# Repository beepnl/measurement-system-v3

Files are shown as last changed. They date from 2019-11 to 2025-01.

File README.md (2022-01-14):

# BEEP - base v3
This is a repo containing the files to create the open source hardware for the Beep measurement system version 3.

This version features a:

- Stainless steel (easy to assemble) frame
- 1 weight sensor
- 1-5 temperature sensors
- 1 mic for on board audio FFT analysis
- Custom developed PCB (by Ideetron) with Nordic nRF BLE and LoRa

The BEEP base is part of the complete [BEEP system](https://github.com/beepnl/BEEP)

## Measurement system parts

The measurement system frame holds the weight sensor and the electonics box housing, and functions as a stiff weighing frame construction.

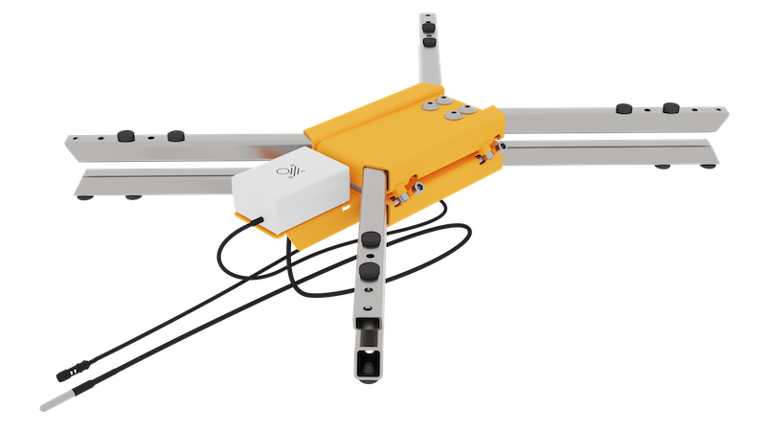
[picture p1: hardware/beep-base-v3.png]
BEEP base v3


### hardware/frame
The folder 'frame' contains the drawings of the stainless steel parts and the standard waterproof casing drill holes. 

### hardware/pcb
The pcb of the measurement system contains a lot of features, that can be seen in the image below:
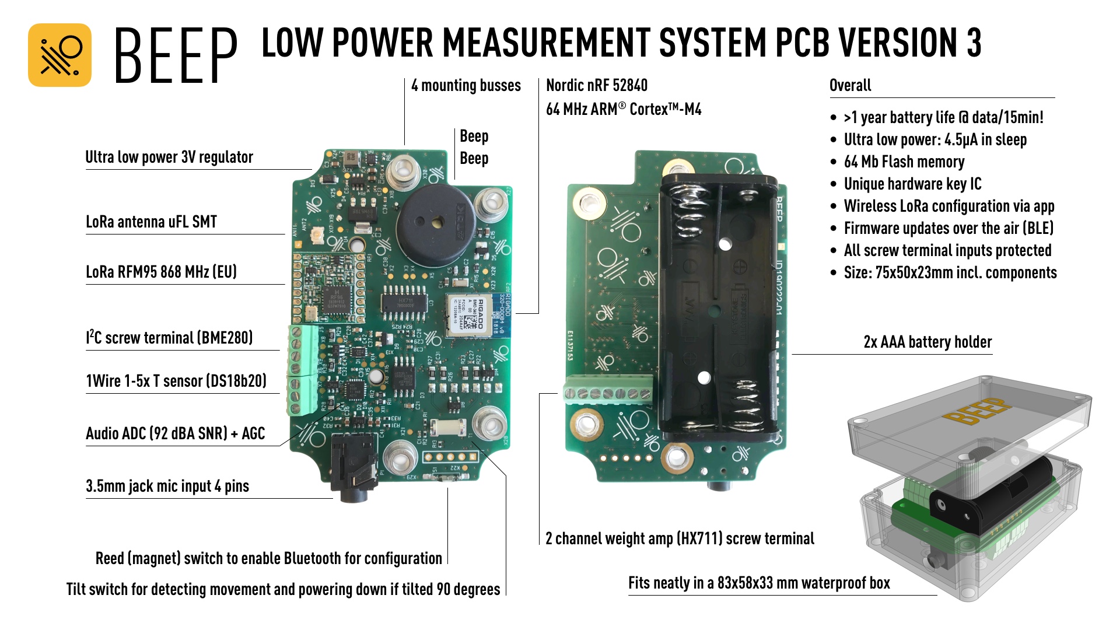
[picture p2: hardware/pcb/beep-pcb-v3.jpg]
BEEP base - PCB v3


The folder contains the gerber files and the schematic. A print layout is added to see find the exact wire locations of the screw terminals

With the Gerber files, you can directly order a PCB. It contains all files required for the manufacturing of the PCB. 

## Assembly

The assembly is straight forward and can be seen in this video:
[BEEP base - Assembly](https://youtu.be/ZGfoobvGa-Y)

## Firmware
The firmware for the BEEP base v3 PCB is available at: https://github.com/beepnl/beep-base-firmware

## Improvements
If you have improvements, or ideas for creating a better frame, please subscribe to our [Slack channel](beep-global.slack.com) explaining your thoughts. 

Or just fork this repo, and do a pull request with you adjustments, or additions.

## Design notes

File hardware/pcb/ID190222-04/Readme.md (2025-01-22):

# Changes ID190222-04

- More space for J6 (1 wire 3 pin header)
- Through holes for S1 (on/off switch) bigger
- Version number bump to ID190222-04

NB: The component placement file is the .rep file

# PCB layout

## Top
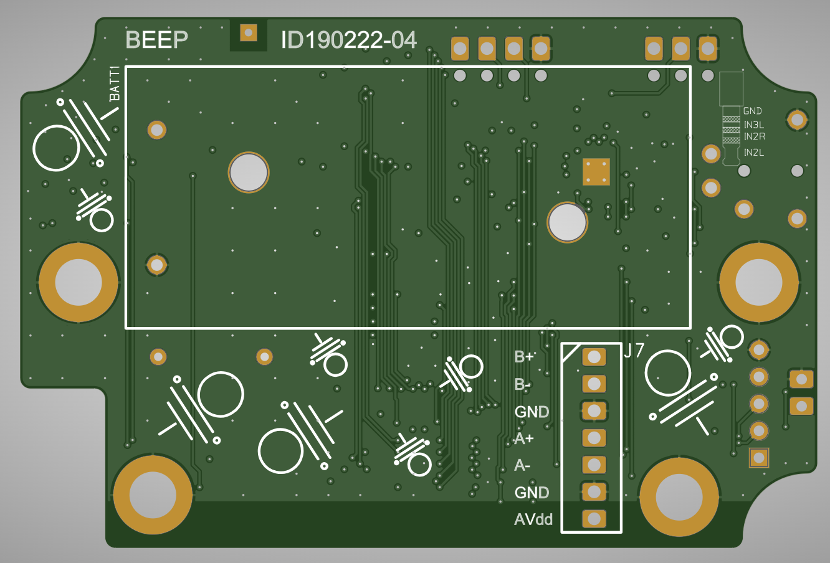
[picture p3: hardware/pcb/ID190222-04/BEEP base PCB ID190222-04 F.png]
PCB top


## Bottom
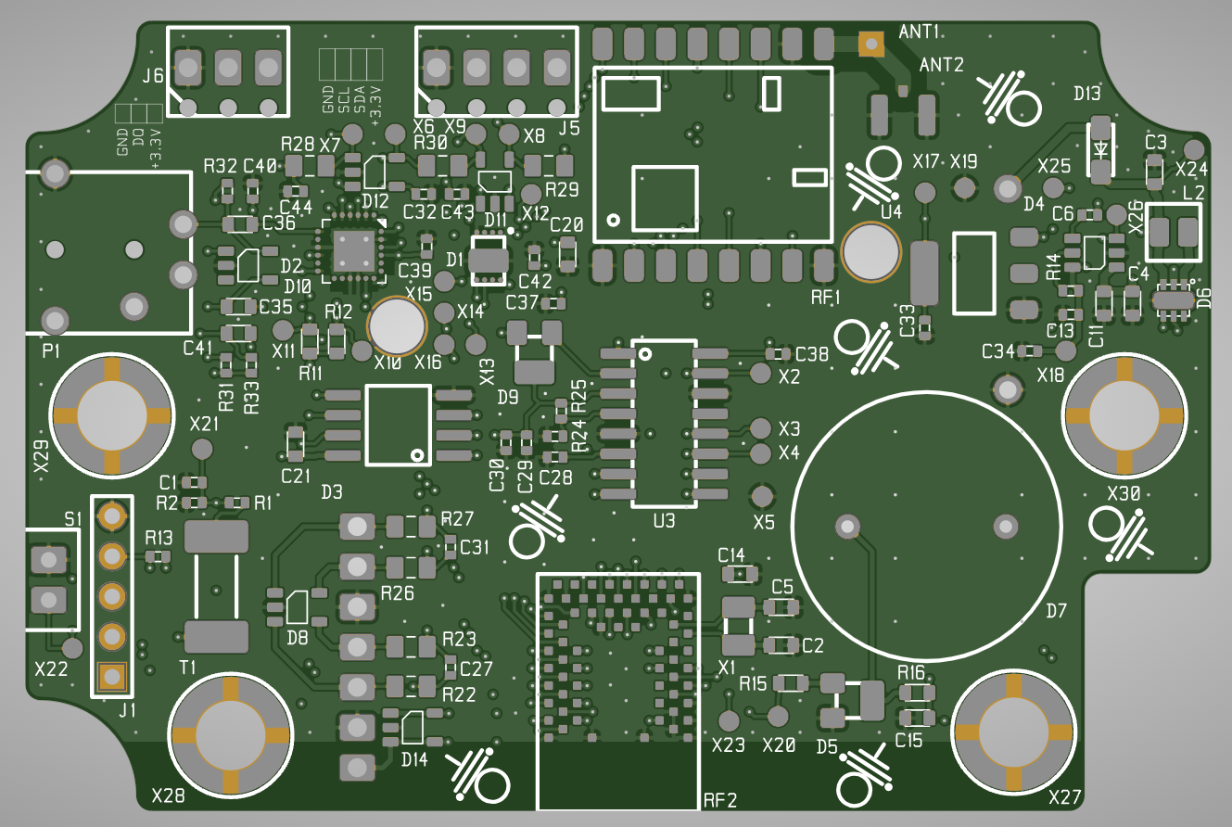
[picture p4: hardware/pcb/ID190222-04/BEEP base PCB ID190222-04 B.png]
PCB bottom


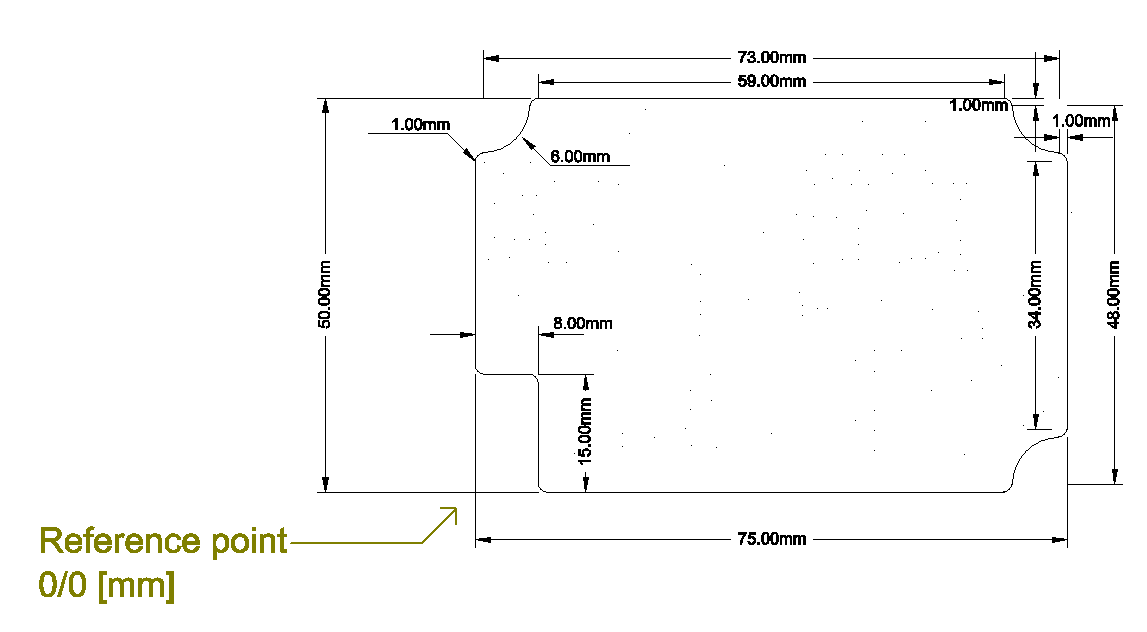
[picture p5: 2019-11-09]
hardware/pcb/pcb-size.png

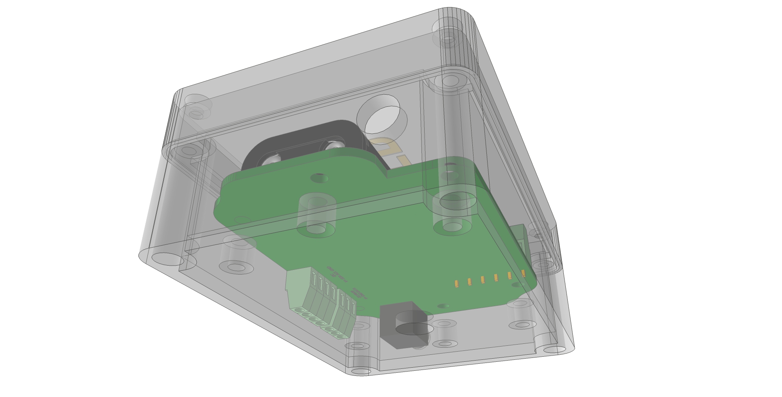
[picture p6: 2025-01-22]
hardware/frame/2019-11-01/beep-pcb-v3-in-box.jpg

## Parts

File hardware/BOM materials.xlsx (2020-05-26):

NB | Amount | DESCRIPTION | MANUFACTURER | TYPE | SUPPLIER | REMARK
1 | 1 | Loadcell | Bosche | H40A a 150KG | bosche.eu | Any 4 wire loadcell will work. However the by us selected loadcell has the most stable results we found
2 | 1 | Temperature Sensor |  | DS20B18 |  | This is a 1 wire system, you can add up to 5 sensors in parallel without any problems.
3 | 1 | Microphone |  | Lavalier Condenser Microphones 3.5mm | https://www.aliexpress.com/item/33003154464.html | TLV320ADC3100 is used as AD converter, any 3 or 4 pin 3,5mm electret microphone will work
4 | 2 | Bateries | Enigizer | L92 |  | Please use 1,5v lithuim cells to ensure you can use the scale for at least a year on one set of batteries when measuring and sending data every 15 minutes

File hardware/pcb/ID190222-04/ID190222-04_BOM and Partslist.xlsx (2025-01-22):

 | donderdag 27 oktober 2022
 | ID190222-03
 | Total number of components: | 82
NB | REF | VALUE | DESCRIPTION | MANUFACTURER | TYPE | SUPPLIER | ORDER CODE | CLASS | REMARK
1 | R14 | 0E_0402 | Resistor 0E 0402 63mW | Vishay | CRCW04020000Z0ED | Farnell | 1469661 | 1
4 | R22 | 100E_0805 | Resistor 100E 1% 0.1W C0805 | Vishay | CRCW0805100RFKEAHP | Farnell | 1738946 | 1
 | R23 | 100E_0805 | Resistor 100E 1% 0.1W C0805 | Vishay | CRCW0805100RFKEAHP | Farnell | 1738946 | 1
 | R26 | 100E_0805 | Resistor 100E 1% 0.1W C0805 | Vishay | CRCW0805100RFKEAHP | Farnell | 1738946 | 1
 | R27 | 100E_0805 | Resistor 100E 1% 0.1W C0805 | Vishay | CRCW0805100RFKEAHP | Farnell | 1738946 | 1
13 | C13 | 100nF 0402 | Capacitor Ceramic 100nF X7R 0402 | TDK | C1005X7R1E104K050BB | Farnell | 2525045 | 1
 | C27 | 100nF 0402 | Capacitor Ceramic 100nF X7R 0402 | TDK | C1005X7R1E104K050BB | Farnell | 2525045 | 1
 | C28 | 100nF 0402 | Capacitor Ceramic 100nF X7R 0402 | TDK | C1005X7R1E104K050BB | Farnell | 2525045 | 1
 | C29 | 100nF 0402 | Capacitor Ceramic 100nF X7R 0402 | TDK | C1005X7R1E104K050BB | Farnell | 2525045 | 1
 | C31 | 100nF 0402 | Capacitor Ceramic 100nF X7R 0402 | TDK | C1005X7R1E104K050BB | Farnell | 2525045 | 1
 | C32 | 100nF 0402 | Capacitor Ceramic 100nF X7R 0402 | TDK | C1005X7R1E104K050BB | Farnell | 2525045 | 1
 | C37 | 100nF 0402 | Capacitor Ceramic 100nF X7R 0402 | TDK | C1005X7R1E104K050BB | Farnell | 2525045 | 1
 | C38 | 100nF 0402 | Capacitor Ceramic 100nF X7R 0402 | TDK | C1005X7R1E104K050BB | Farnell | 2525045 | 1
 | C39 | 100nF 0402 | Capacitor Ceramic 100nF X7R 0402 | TDK | C1005X7R1E104K050BB | Farnell | 2525045 | 1
 | C40 | 100nF 0402 | Capacitor Ceramic 100nF X7R 0402 | TDK | C1005X7R1E104K050BB | Farnell | 2525045 | 1
 | C42 | 100nF 0402 | Capacitor Ceramic 100nF X7R 0402 | TDK | C1005X7R1E104K050BB | Farnell | 2525045 | 1
 | C43 | 100nF 0402 | Capacitor Ceramic 100nF X7R 0402 | TDK | C1005X7R1E104K050BB | Farnell | 2525045 | 1
 | C44 | 100nF 0402 | Capacitor Ceramic 100nF X7R 0402 | TDK | C1005X7R1E104K050BB | Farnell | 2525045 | 1
1 | C6 | 100pF 0402 | Capacitor Ceramic 100pF C0G 0402 | Kemet | C0402C101K3GACTU | Farnell | 2581019 | 1
2 | R13 | 10K0_0402 | Resistor 10K0 5% 0.0625W C0402 | Tyco | CRG0402J10K-10 | Farnell | 1174160 | 1
 | R25 | 10K0_0402 | Resistor 10K0 5% 0.0625W C0402 | Tyco | CRG0402J10K-10 | Farnell | 1174160 | 1
1 | C1 | 10nF 0402 | Capacitor Ceramic 10NF X7R 0402 | Murata | GRM155R71H103KA88D | Farnell | 1828887 | 1
3 | C30 | 10uF 0402 6.3V | Capacitor Ceramic 10u X5R 0402 | muRata | GRM155R60J106ME44D | Farnell | 2666402 | 1
 | C33 | 10uF 0402 6.3V | Capacitor Ceramic 10u X5R 0402 | muRata | GRM155R60J106ME44D | Farnell | 2666402 | 1
 | C34 | 10uF 0402 6.3V | Capacitor Ceramic 10u X5R 0402 | muRata | GRM155R60J106ME44D | Farnell | 2666402 | 1
4 | C11 | 10uF 0603 | Capacitor Ceramic 10uF X5R 0603 | TDK | C1608X5R1E106M080AC | Farnell | 2525099 | 1
 | C15 | 10uF 0603 | Capacitor Ceramic 10uF X5R 0603 | TDK | C1608X5R1E106M080AC | Farnell | 2525099 | 1
 | C3 | 10uF 0603 | Capacitor Ceramic 10uF X5R 0603 | TDK | C1608X5R1E106M080AC | Farnell | 2525099 | 1
 | C4 | 10uF 0603 | Capacitor Ceramic 10uF X5R 0603 | TDK | C1608X5R1E106M080AC | Farnell | 2525099 | 1
1 | R1 | 1k00_0402 | Resistor 1k00 C0402 1% 0.063W | Walsin | WR04X1001FTL | Farnell | 2502496 | 1
4 | R11 | 1k20_0603 | Resistor 1k20 C0603 1% 0.1W | Panasonic | ERJ3EKF1201V | Farnell | 2303150 | 1
 | R12 | 1k20_0603 | Resistor 1k20 C0603 1% 0.1W | Panasonic | ERJ3EKF1201V | Farnell | 2303150 | 1
 | R15 | 1k20_0603 | Resistor 1k20 C0603 1% 0.1W | Panasonic | ERJ3EKF1201V | Farnell | 2303150 | 1
 | R16 | 1k20_0603 | Resistor 1k20 C0603 1% 0.1W | Panasonic | ERJ3EKF1201V | Farnell | 2303150 | 1
2 | C20 | 220NF 25V 0603 | Capacitor Ceramic 220nF SMD 0603 25V | Epcos | B37931K0224K60 | Farnell | 8805644 | 1
 | C21 | 220NF 25V 0603 | Capacitor Ceramic 220nF SMD 0603 25V | Epcos | B37931K0224K60 | Farnell | 8805644 | 1
1 | BATT1 | 2468 | Battery holder for 2AAA batteries | Kyestone | 2468 | Farnell | 1650679 | 2
3 | R31 | 2k2_0402 | Resistor 2k2 1% 63mW C0402 | Vishay | CRCW04022K20FKED | Farnell | 2140802 | 1
 | R32 | 2k2_0402 | Resistor 2k2 1% 63mW C0402 | Vishay | CRCW04022K20FKED | Farnell | 2140802 | 1
 | R33 | 2k2_0402 | Resistor 2k2 1% 63mW C0402 | Vishay | CRCW04022K20FKED | Farnell | 2140802 | 1
1 | P1 | 3.5MM JACK | 3.5mm Audio Jack Connector THT 4-positions | CUI | 3.5mm_Jack | Mouser | 490-SJ-43515TS | 2
1 | R2 | 3M3_0402 | Resistor 3M30 C0402 1% 0.063W | Vishay | CRCW04023M30FKED | Farnell | 2141102 | 1
1 | L2 | 3U3H-1.7A | Spoel 3.3 uH 1.7A 3x3 | Wurth | WE-MAPI | Farnell | 2361920 | 2
3 | C35 | 470NF 0603 | Capacitor Ceramic 470NF X7R 0603 | TDK | C1608X7R1H474K080AC | Farnell | 2346908 | 1
 | C36 | 470NF 0603 | Capacitor Ceramic 470NF X7R 0603 | TDK | C1608X7R1H474K080AC | Farnell | 2346908 | 1
 | C41 | 470NF 0603 | Capacitor Ceramic 470NF X7R 0603 | TDK | C1608X7R1H474K080AC | Farnell | 2346908 | 1
3 | R28 | 4K70_0805 | Resistor 4K70 1% 0.1W C0805 | Vishay | CRCW08054K70FKEA | Farnell | 1469923 | 1
 | R29 | 4K70_0805 | Resistor 4K70 1% 0.1W C0805 | Vishay | CRCW08054K70FKEA | Farnell | 1469923 | 1
 | R30 | 4K70_0805 | Resistor 4K70 1% 0.1W C0805 | Vishay | CRCW08054K70FKEA | Farnell | 1469923 | 1
1 | C14 | 4U7 0603 | Capacitor Ceramic 4u7 X7R 0603 | TDK | C1608X7S1A475K080AC | Farnell | 2528771 | 1
2 | C2 | 6pF 0603 | Capacitor Ceramic 6pF NP0 0603 | Walsin | 0603N6R0D500CT | Farnell | 2496912 | 1
 | C5 | 6pF 0603 | Capacitor Ceramic 6pF NP0 0603 | Walsin | 0603N6R0D500CT | Farnell | 2496912 | 1
1 | R24 | 8k2_0402 | Resistor 8k2 0402 63mW | Vishay | CRCW04028K20FKED | Farnell | 2140851 | 1
1 | D1 | ATECC608A-MAHDA | CryptoAuthentication Devie | Microchip | ATECC608-MAHDA | Mouser | 556-ATECC608AMAHDAS | 2
1 | D5 | BC850C | NPN general purpose transistor | NPX | BC850C | Farnell | 1081241 | 2
1 | RF2 | BMD-340 | nRF52840 device Rigado | Rigado | 377-BMD-340-A-R | Mouser | BMD-340-A-R | 2
1 | ANT2 | CL331-0471 | U-FL connector SMD | Hirose | CL331-0471 | Fanell | CL331-0471 | 2
1 | D13 | CRS08 | Schottky diode 1.5A 30V 360mV | Toshiba | CRS08 | Farnell | 1300796 | 2
5 | D11 | ESDS304DBVR | 4-Channel ESD diode 3.6Vrwm SOT23-5 | Texas Instruments | ESDS304DBVR | Mouser | 595-ESDS304DBVR | 2
 | D12 | ESDS304DBVR | 4-Channel ESD diode 3.6Vrwm SOT23-5 | Texas Instruments | ESDS304DBVR | Mouser | 595-ESDS304DBVR | 2
 | D14 | ESDS304DBVR | 4-Channel ESD diode 3.6Vrwm SOT23-5 | Texas Instruments | ESDS304DBVR | Mouser | 595-ESDS304DBVR | 2
 | D2 | ESDS304DBVR | 4-Channel ESD diode 3.6Vrwm SOT23-5 | Texas Instruments | ESDS304DBVR | Mouser | 595-ESDS304DBVR | 2
 | D8 | ESDS304DBVR | 4-Channel ESD diode 3.6Vrwm SOT23-5 | Texas Instruments | ESDS304DBVR | Mouser | 595-ESDS304DBVR | 2
1 | U3 | HX711 | 24-Bit Analog-to-Digital Converter (ADC) | AVIA SEMICONDUCTOR | HX711 | - | HX711 | 2
1 | D9 | MMBT4403 | PNP transistor SOT23-3 | Diodes | MMBT4403 | Farnell | 2061460 | 2
1 | J6 | MPT0.5-3_2.54 | 3 polige pinheader 2.54mm raster Phoenix 1725669 | Phoenix | MPT0.5-3_2.54 | Phoenix | 1725669 | 2
1 | J5 | MPT0.5-4_2.54 | 4 polige pinheader 2.54mm raster Phoenix 1725672 | Phoenix | MPT0.5-4_2.54 | Phoenix | 1725672 | 2
1 | J7 | MPT0.5-7_2.54 | 7 polige pinheader 2.54mm raster Phoenix 1725708 | Phoenix | MPT0.5-7_2.54 | Phoenix | 1725708 | 2
1 | D3 | MX25R6435F | Flash Memory Serial NOR 64 Mbit SPI SOP-8 | Macronix | MX25R6435F | Farnell | MX25R6435FM2IH0 | 2
1 | X1 | NX3215SA 32.768KHz | NX3215SA 32.768KHz EXS00A-MU00376 6pF | NDK | NX3215SA | NDK | NX3215SA | 2
1 | D7 | PS1720P02 | Buzzer 2kHz 3V req. Waves 70dBA 17mm dia. 10mm leads | TDK | PS1720P02 | Farnell | 1669968 | 2
1 | RF1 | RFM95 | FSK Transceiver | HOPE-RF | RFM95 | HOPE-RF | RFM95 | 2 | Will be supplied bij Ideetron
1 | S1 | RI-80SMD0515-G2 | SMD Reed switch | COMUS | RI-80SMD | Farnell | 1081704 | 2
1 | T1 | SQ-SEN-645B-ICT | Tilt Sensor Zero Power | Signalquest | SQ-SEN-645B-ICT | Signalquest | SQ-SEN-645B-ICT | 2
1 | U4 | TLV1117LV18DCYR | Fixed 1.8V LDO 2V - 5.5v | Texas Instruments | TLV1117LV18DCYR | Farnell | 2492356 | 2
1 | D10 | TLV320ADC3100 | Low Power stereo ADC I2S + I2C control | Texas Instruments | TLV320ADC3100IRGET | Mouser | 595-V320ADC3100IRGET | 2
1 | D4 | TPS22917 | Load switch 1V-5.5V 2A 0.5uA On 10nA Off SOT23-6 | Ti | TPS22917 | Farnell | 2851323 | 2
1 | D6 | TPS61291 | Boost converter with bypass | TI | TPS61291 | Farnell | 2450171 | 2
4 | X27 | WA-SMST 3.3X4 | SMD spacer 3.3mm dia 4mm Length | Wurth | WA-SMST | Farnell | 2497625 | 2
 | X28 | WA-SMST 3.3X4 | SMD spacer 3.3mm dia 4mm Length | Wurth | WA-SMST | Farnell | 2497625 | 2
 | X29 | WA-SMST 3.3X4 | SMD spacer 3.3mm dia 4mm Length | Wurth | WA-SMST | Farnell | 2497625 | 2
 | X30 | WA-SMST 3.3X4 | SMD spacer 3.3mm dia 4mm Length | Wurth | WA-SMST | Farnell | 2497625 | 2
Class
1 | Allowed to place an equivalent without approval
2 | Only place an other component after approval

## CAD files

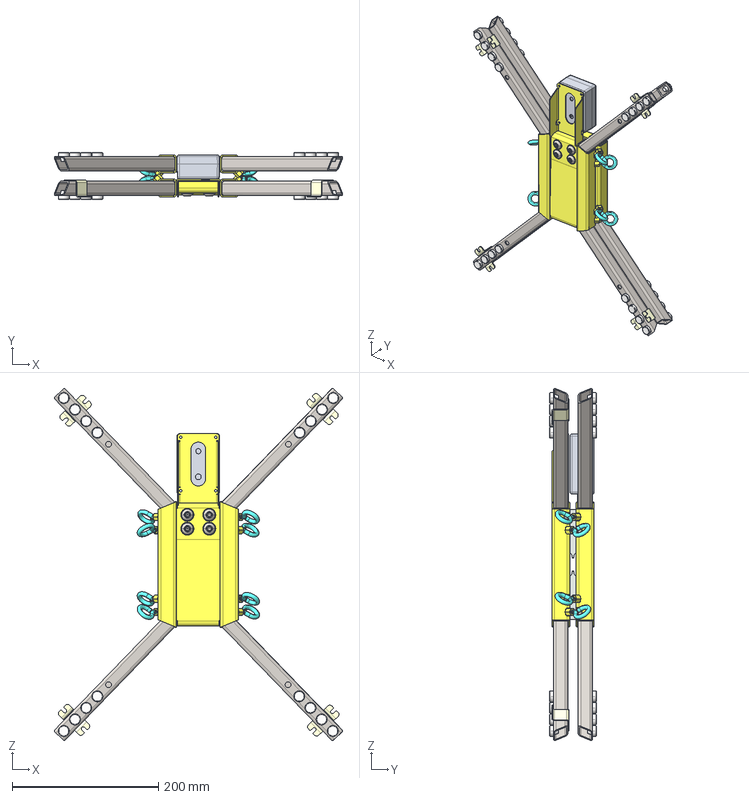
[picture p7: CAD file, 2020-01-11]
hardware/frame/2019-11-01/BMS-V3_2019-11-02.stp
394.7 x 64.0 x 481.7 mm
H40A-C3-0150
BMS-V3_FRAME_CENTRE x 2
BMS-V3_FRAME_TUBE x 4
M6_NUT x 8
BMS-V3_SUPPORT_L x 4
BUFFERVOET_D15_D8-5-7 x 32
BMS-V3_SUPPORT_R x 4
M8X20 x 8
M6_WING_THREAD x 8
EC_BOX_83X58X33
BMS-V3_FRAME_EC_BRACKET
BMS-V3_CLAMP x 4

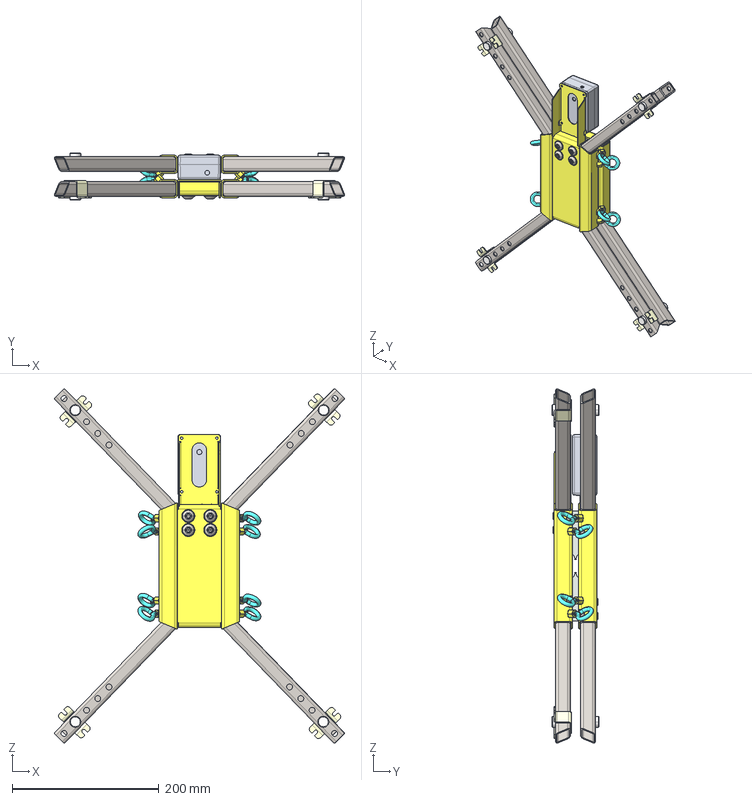
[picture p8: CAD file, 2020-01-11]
hardware/frame/2019-12-06/BMS-V3_2019-12-06.stp
394.7 x 64.0 x 481.7 mm
H40A-C3-0150
BMS-V3_FRAME_CENTRE x 2
BMS-V3_FRAME_TUBE x 4
M6_NUT x 8
BMS-V3_SPACER x 2
BMS-V3_SUPPORT_L x 4
BUFFERVOET_D15_D8-5-7 x 8
BMS-V3_SUPPORT_R x 4
M8X20 x 8
M6_WING_THREAD x 8
EC_BOX_83X58X33
BMS-V3_FRAME_EC_BRACKET
BMS-V3_CLAMP x 4

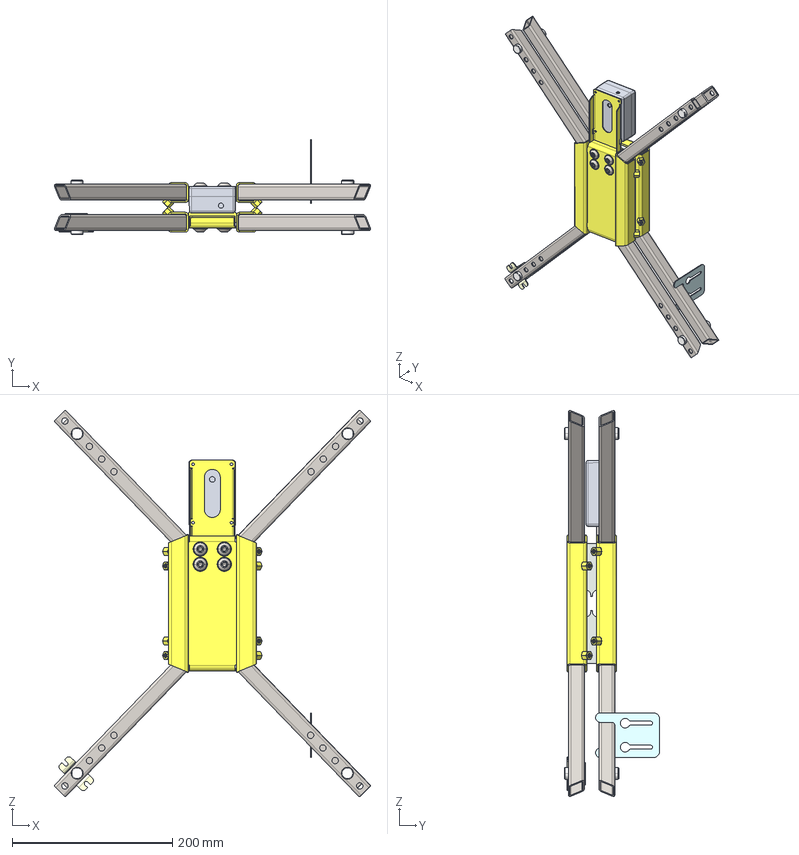
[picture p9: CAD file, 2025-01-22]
hardware/frame/2020-09-07/BMS-V3_2020-09-07.stp
395.1 x 119.0 x 482.1 mm
H40A-C3-0150
BMS-V3_FRAME_CENTRE x 2
BMS-V3_FRAME_TUBE x 4
M6_NUT x 8
BMS-V3_SPACER x 2
BMS-V3_SUPPORT_L x 4
BUFFERVOET_D15_D8-5-7 x 8
BMS-V3_SUPPORT_R x 4
M8X20 x 8
M6_WING_ASM x 8
EC_BOX_83X58X33
BMS-V3_FRAME_EC_BRACKET
BMS-V3_CLAMP
BMS-V3_FRAME-BRACKET

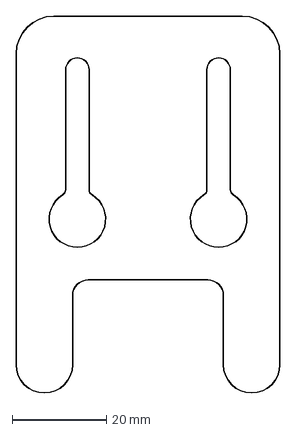
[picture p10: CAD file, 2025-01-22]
hardware/frame/2020-11-20/BMS-V3__2020-11-20 positioning bracket.dxf
56.0 x 80.0 mm

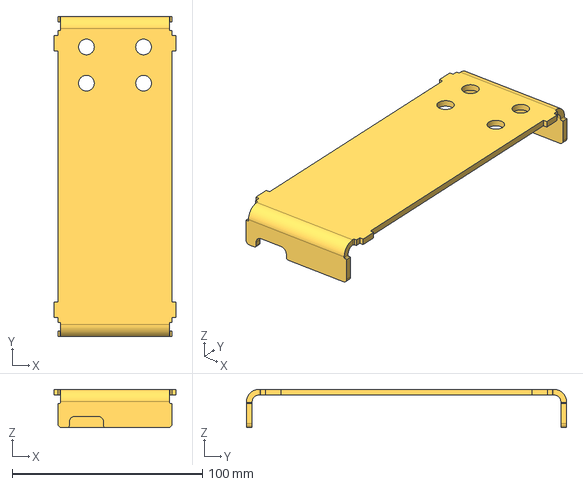
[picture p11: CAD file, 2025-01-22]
hardware/frame/2025-01-21/BMS-V3_FRAME_CENTRE.step
64.0 x 168.0 x 20.0 mm

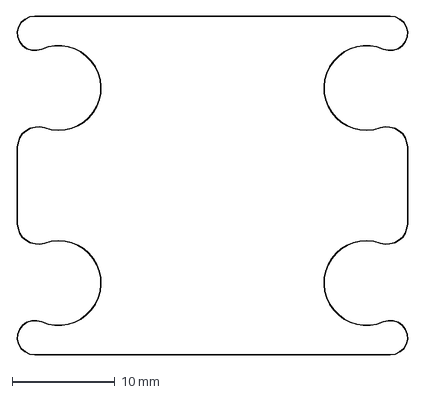
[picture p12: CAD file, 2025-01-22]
hardware/frame/2020-11-20/BMS-Loadcell-spacer.dxf
38.3 x 33.0 mm

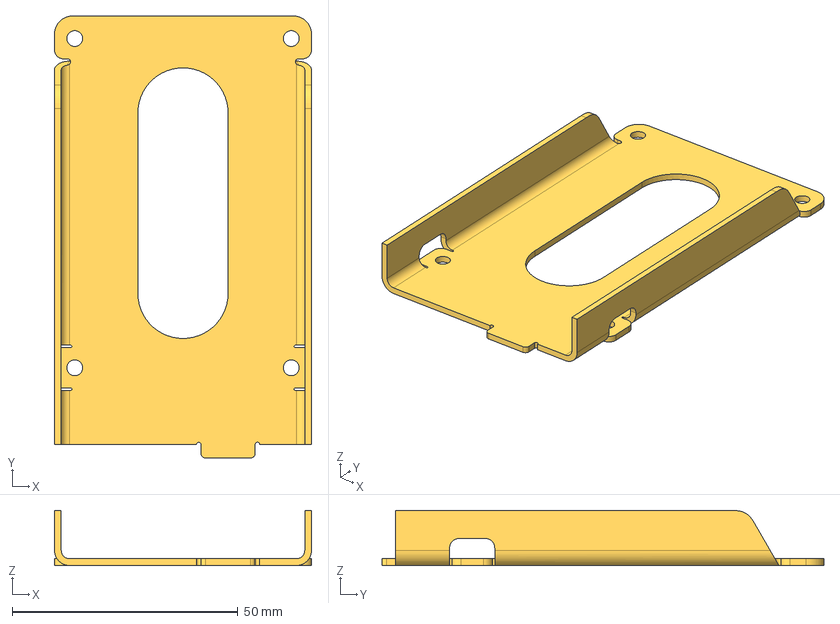
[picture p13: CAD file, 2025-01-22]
hardware/frame/2025-01-21/BMS-V3_FRAME_EC_BRACKET.step
57.0 x 98.0 x 12.2 mm

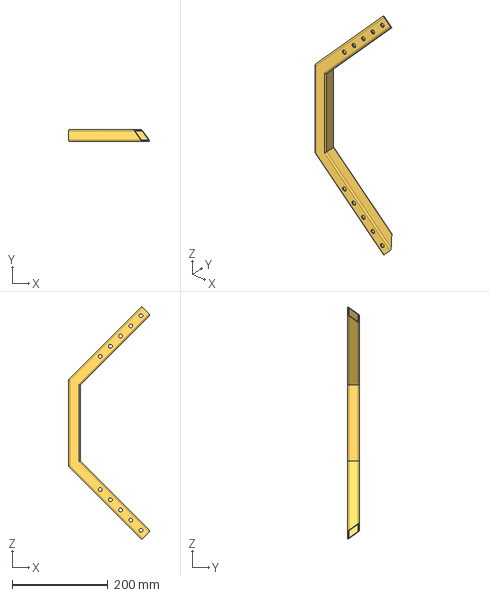
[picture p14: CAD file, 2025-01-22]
hardware/frame/2025-01-21/BMS-v3.7-LEG - Leg one piece.step
169.7 x 25.0 x 483.7 mm

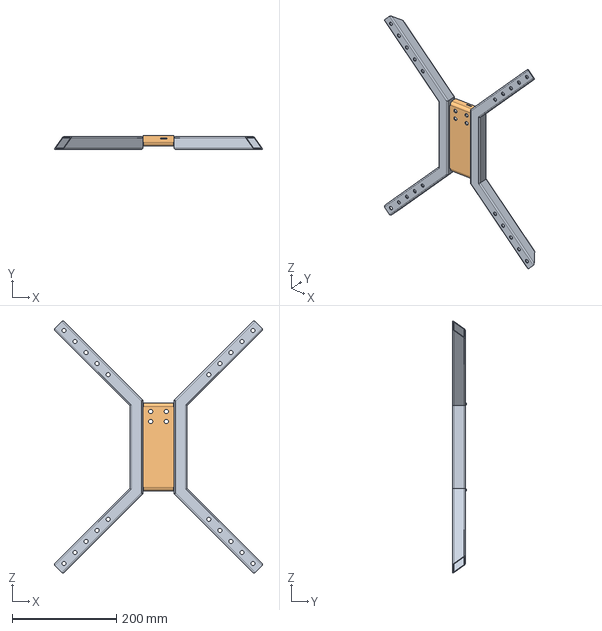
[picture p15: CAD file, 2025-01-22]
hardware/frame/2025-01-21/BMS-v3.7-FRAME-HALF-TOP.step
399.3 x 27.1 x 483.7 mm
Leg one piece x 2
BMS-V3_FRAME_CENTRE

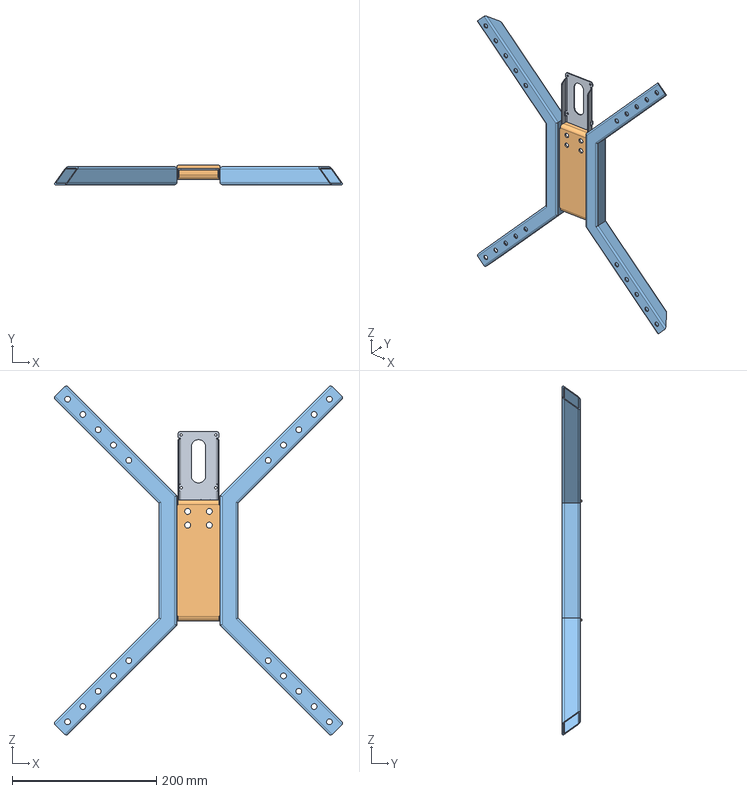
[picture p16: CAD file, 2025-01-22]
hardware/frame/2025-01-21/BMS-v3.7-FRAME-HALF-BOTTOM.step
399.3 x 27.1 x 483.7 mm
BMS-V3_FRAME_EC_BRACKET
BMS-V3_FRAME_CENTRE
Leg one piece x 2

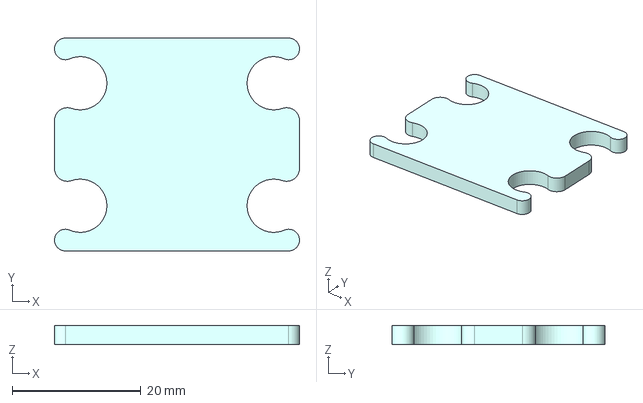
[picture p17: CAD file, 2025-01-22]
hardware/frame/2025-01-21/BMS-V3_SPACER.step
38.0 x 33.0 x 3.00 mm

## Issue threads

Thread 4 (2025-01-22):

CPL file

radektom, 2025-01-22:
Hello, thank you for sharing this great project. Would it be possible to share the CPL (Component Placement List) required for automated PCB assembly? Thank you in advance!

pvgennip, 2025-01-22:
Hi @radektom I just added the latest PCB gerber files for ID190222-04. In the zip are all files you need.

Closed 2025-01-22.

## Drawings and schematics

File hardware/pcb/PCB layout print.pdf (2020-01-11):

## BEEP PCB v3.0 Nordic BLE

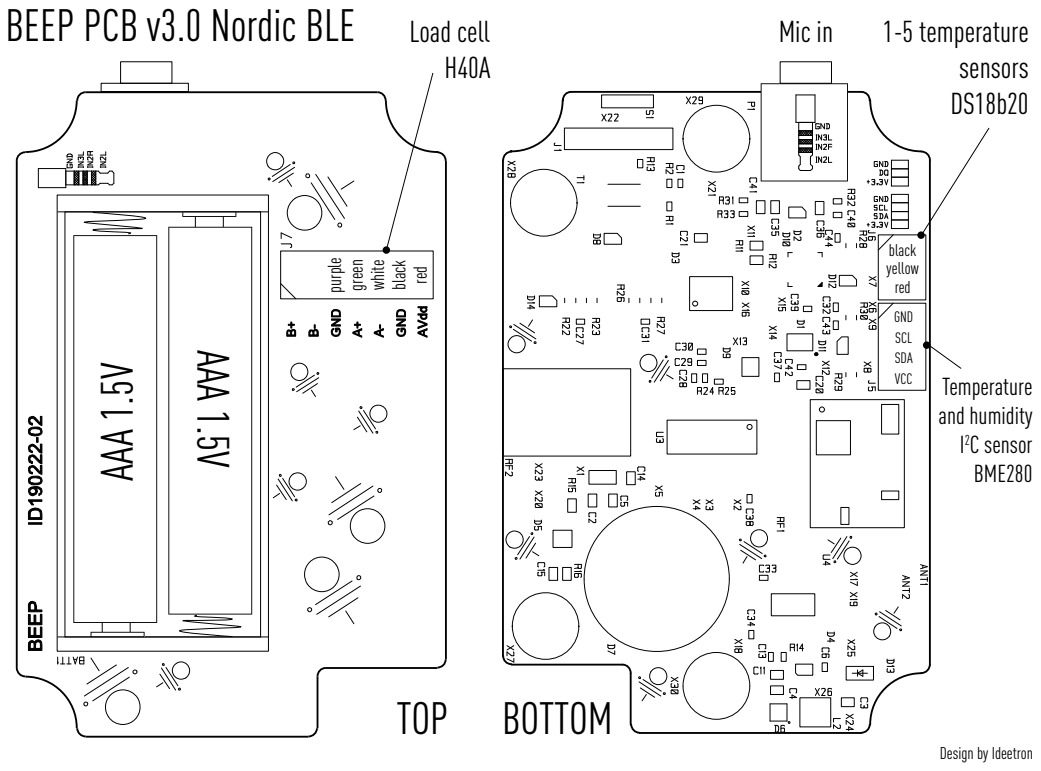
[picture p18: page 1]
TOP BOTTOM; AAA 1.5V; purple green white; black red; Load cell H40A; black yellow red; 1-5 temperature sensors DS18b20; Mic in; GND SCL SDA VCC; Temperature and humidity I; C sensor BME280

Design by Ideetron

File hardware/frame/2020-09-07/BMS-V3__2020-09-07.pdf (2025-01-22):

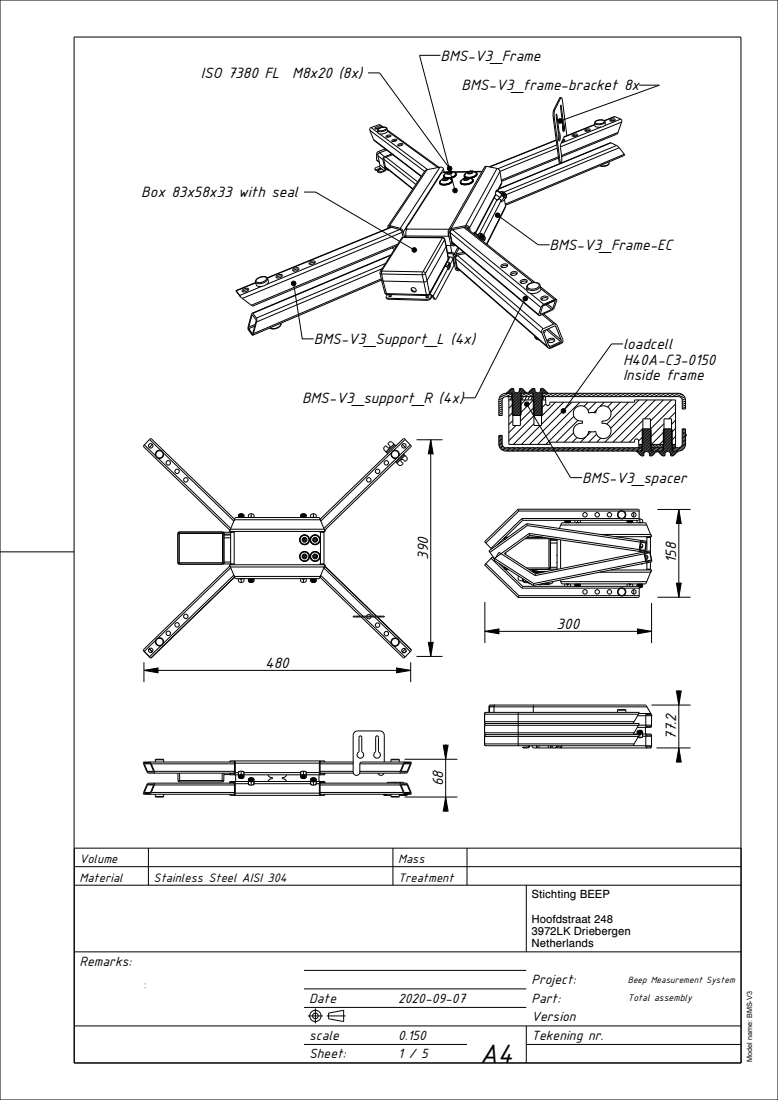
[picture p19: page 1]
Remarks:; Project:; Beep Measurement System; Date; Part:; Total assembly; Version; scale; Tekening nr.; Sheet:; BMS-V3_Frame; ISO 7380 FL M8x20 (8x); loadcell H40A-C3-0150 Inside frame; BMS-V3_spacer; BMS-V3_support_R (4x); BMS-V3_Support_L (4x); BMS-V3_Frame-EC; BMS-V3_frame-bracket 8x

Box 83x58x33 with seal

Volume | | Mass
Material | Stainless Steel AISI 304 | Treatment

Stichting BEEP Hoofdstraat 248 3972LK Driebergen Netherlands

Model name: BMS-V3

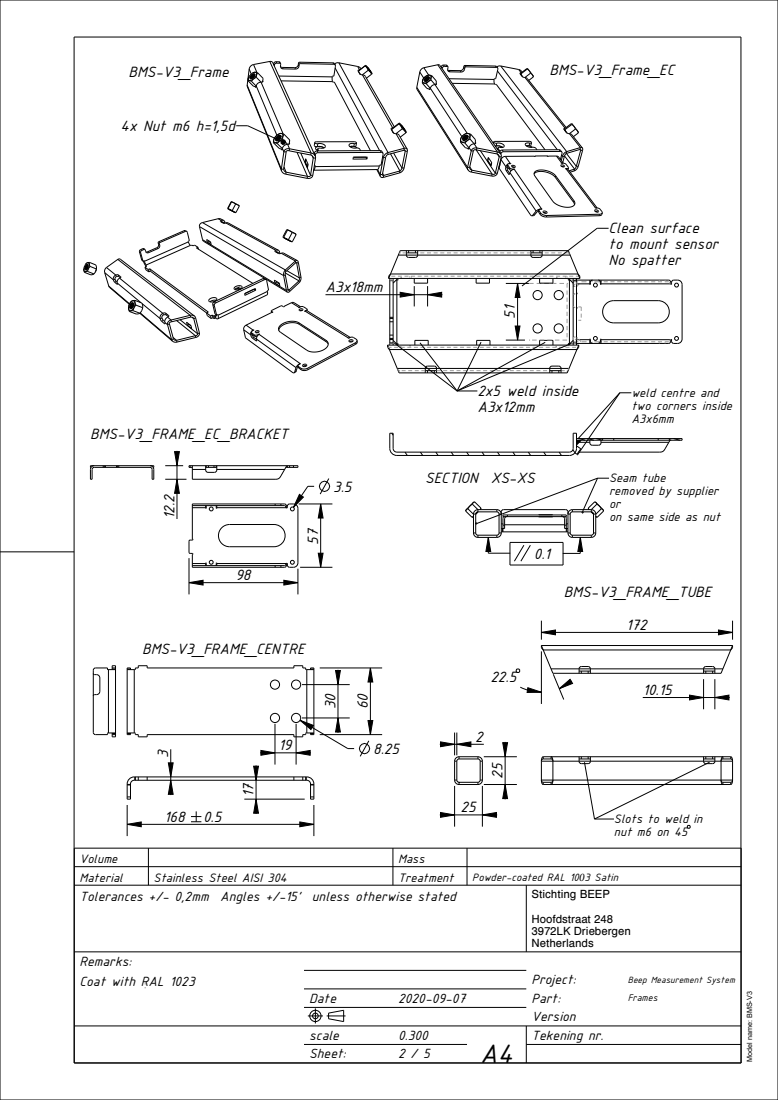
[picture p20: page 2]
Remarks:; Coat with RAL 1023; Project:; Beep Measurement System; Date; Part:; Frames; scale; Tekening nr.; Sheet:; 4x Nut m6 h=1,5d; BMS-V3_FRAME_CENTRE; BMS-V3_FRAME_EC_BRACKET; BMS-V3_FRAME_TUBE; BMS-V3_Frame; BMS-V3_Frame_EC; 2x5 weld inside A3x12mm

Clean surface
to mount sensor
No spatter

weld centre and
two corners inside

SECTION XS-XS

Seam tube
removed by supplier
on same side as nut

Slots to weld in
nut m6 on 45

Volume | | Mass
Material | Stainless Steel AISI 304 | Treatment | Powder-coated RAL 1003 Satin
Tolerances +/- 0,2mm Angles +/-15' unless otherwise stated | Stichting BEEP Hoofdstraat 248 3972LK Driebergen Netherlands

Model name: BMS-V3

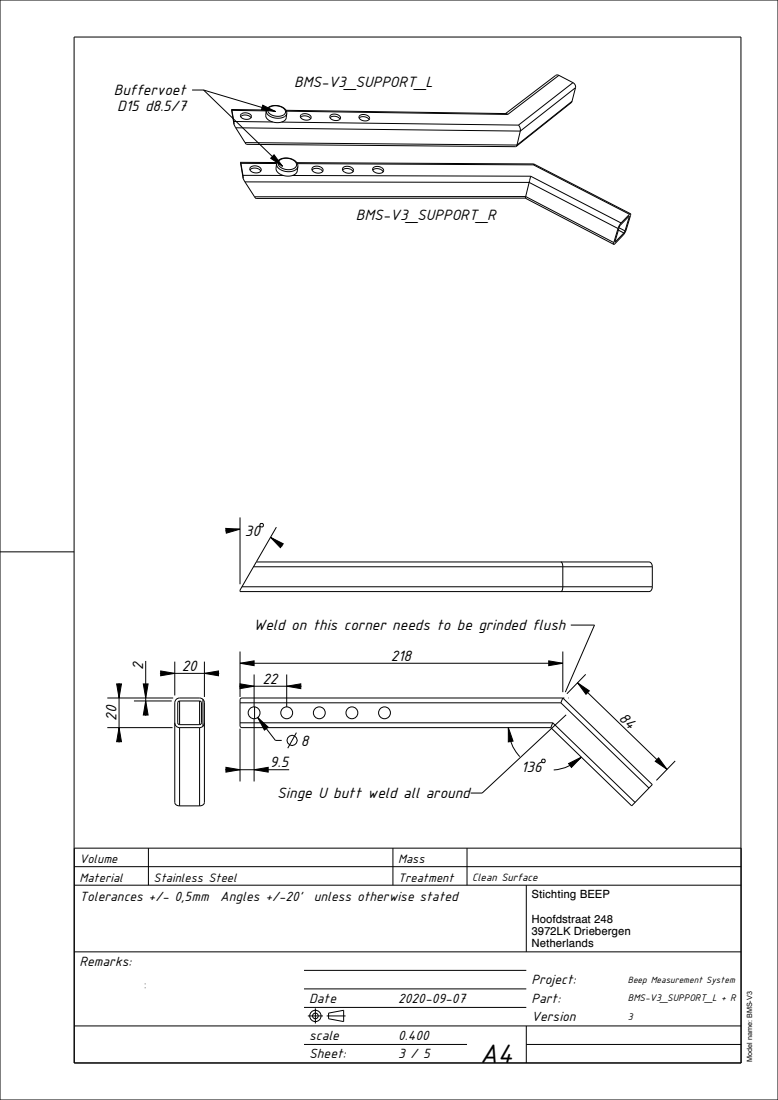
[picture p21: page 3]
Remarks:; Project:; Beep Measurement System; Date; Part:; BMS-V3_SUPPORT_L + R; Version; scale; Sheet:; BMS-V3_SUPPORT_L; BMS-V3_SUPPORT_R; Buffervoet D15 d8.5/7

Weld on this corner needs to be grinded flush

Singe U butt weld all around

Volume | | Mass
Material | Stainless Steel | Treatment | Clean Surface
Tolerances +/- 0,5mm Angles +/-20' unless otherwise stated | Stichting BEEP Hoofdstraat 248 3972LK Driebergen Netherlands

Model name: BMS-V3

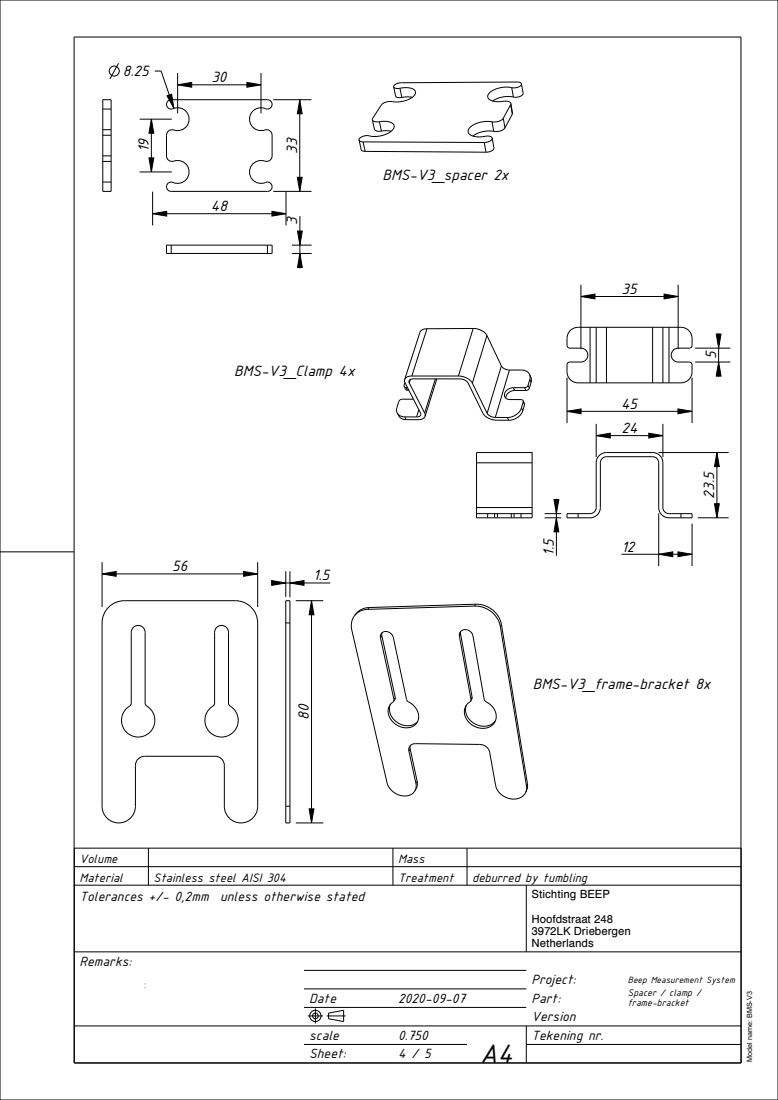
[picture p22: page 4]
Remarks:; Project:; Beep Measurement System; Date; Part:; Spacer / clamp /; frame-bracket; scale; Tekening nr.; Sheet:; BMS-V3_Clamp 4x; BMS-V3_spacer 2x; BMS-V3_frame-bracket 8x

Volume | | Mass
Material | Stainless steel AISI 304 | Treatment | deburred by tumbling
Tolerances +/- 0,2mm unless otherwise stated | Stichting BEEP Hoofdstraat 248 3972LK Driebergen Netherlands

Model name: BMS-V3

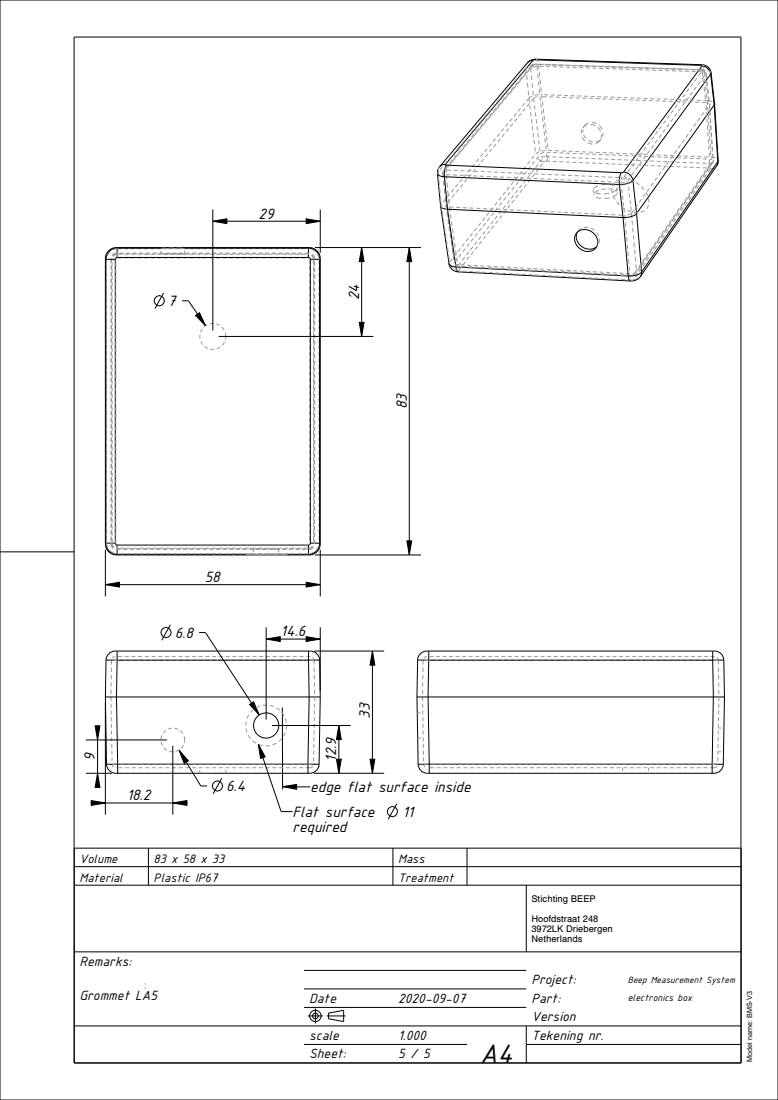
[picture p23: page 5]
Remarks:; Grommet LA5; Project:; Beep Measurement System; Date; Part:; electronics box; scale; Tekening nr.; Sheet:; Flat surface

edge flat surface inside

required

Volume | 83 x 58 x 33 | Mass
Material | Plastic IP67 | Treatment

Stichting BEEP Hoofdstraat 248 3972LK Driebergen Netherlands

Model name: BMS-V3

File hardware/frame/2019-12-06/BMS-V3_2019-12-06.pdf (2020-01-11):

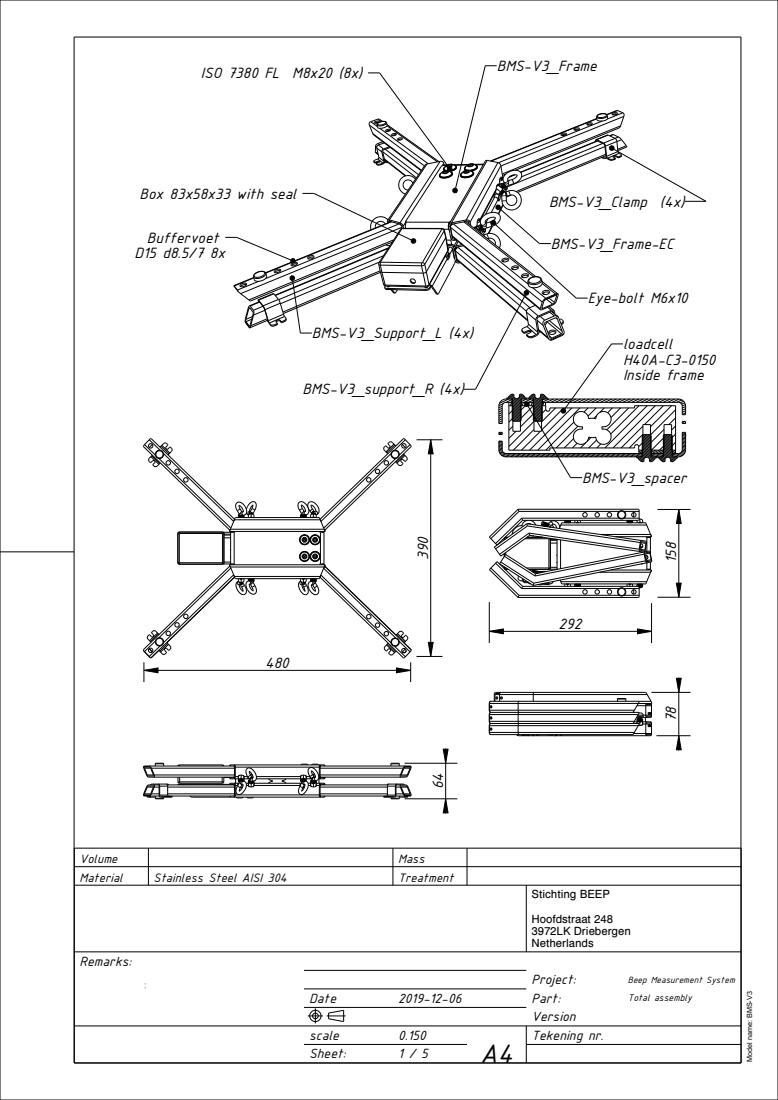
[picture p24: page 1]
Remarks:; Project:; Beep Measurement System; Date; Part:; Total assembly; Version; scale; Tekening nr.; Sheet:; loadcell H40A-C3-0150 Inside frame; Eye-bolt M6x10; BMS-V3_spacer; BMS-V3_support_R (4x); BMS-V3_Support_L (4x); BMS-V3_Frame-EC; Buffervoet D15 d8.5/7 8x

BMS-V3_Frame ISO 7380 FL M8x20 (8x)

BMS-V3_Clamp (4x) Box 83x58x33 with seal

Volume | | Mass
Material | Stainless Steel AISI 304 | Treatment

Stichting BEEP Hoofdstraat 248 3972LK Driebergen Netherlands

Model name: BMS-V3

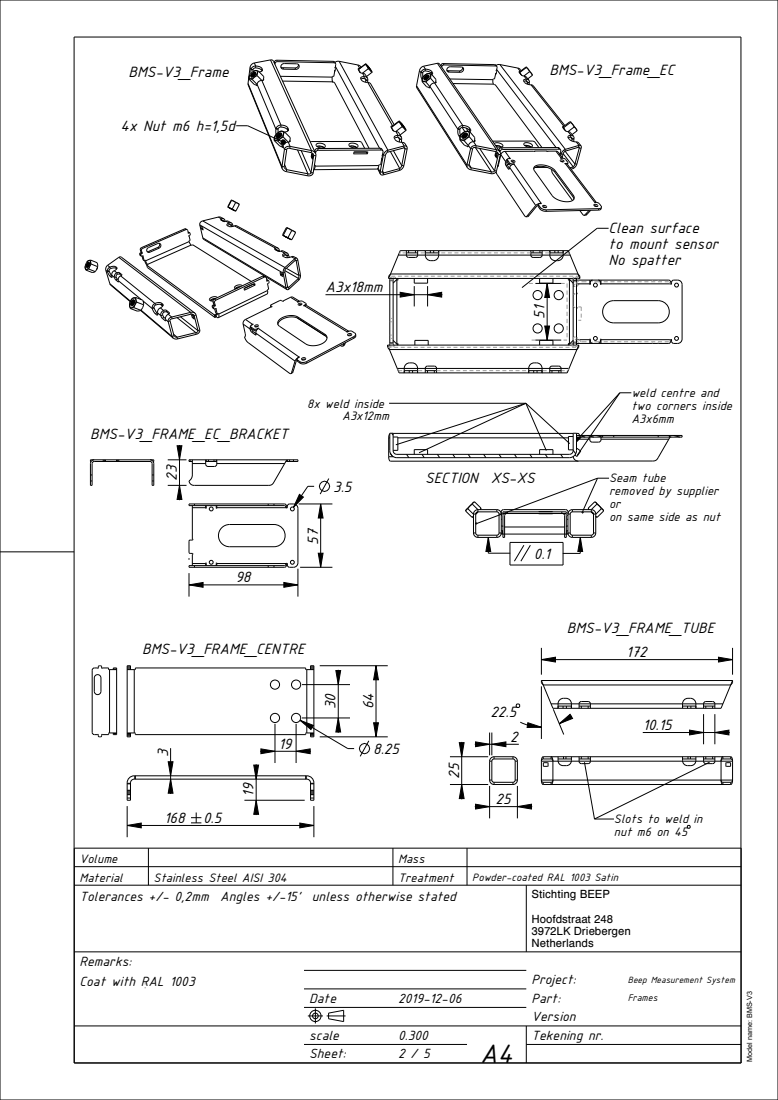
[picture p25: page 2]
Remarks:; Coat with RAL 1003; Project:; Beep Measurement System; Date; Part:; Frames; scale; Tekening nr.; Sheet:; 4x Nut m6 h=1,5d; BMS-V3_FRAME_CENTRE; BMS-V3_FRAME_EC_BRACKET; BMS-V3_FRAME_TUBE; BMS-V3_Frame; BMS-V3_Frame_EC; 8x weld inside A3x12mm

Clean surface
to mount sensor
No spatter

weld centre and
two corners inside

SECTION XS-XS

Seam tube
removed by supplier
on same side as nut

Slots to weld in
nut m6 on 45

Volume | | Mass
Material | Stainless Steel AISI 304 | Treatment | Powder-coated RAL 1003 Satin
Tolerances +/- 0,2mm Angles +/-15' unless otherwise stated | Stichting BEEP Hoofdstraat 248 3972LK Driebergen Netherlands

Model name: BMS-V3

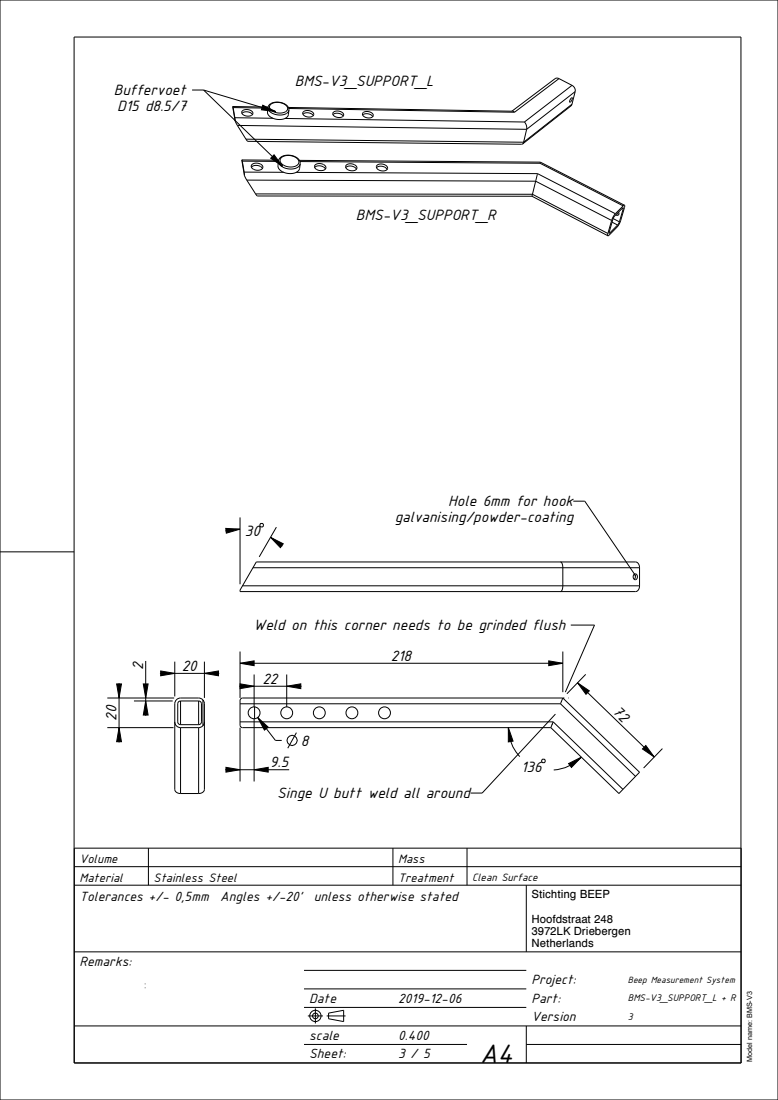
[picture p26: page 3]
Remarks:; Project:; Beep Measurement System; Date; Part:; BMS-V3_SUPPORT_L + R; Version; scale; Sheet:; BMS-V3_SUPPORT_L; BMS-V3_SUPPORT_R; Buffervoet D15 d8.5/7

Hole 6mm for hook
galvanising/powder-coating

Weld on this corner needs to be grinded flush

Singe U butt weld all around

Volume | | Mass
Material | Stainless Steel | Treatment | Clean Surface
Tolerances +/- 0,5mm Angles +/-20' unless otherwise stated | Stichting BEEP Hoofdstraat 248 3972LK Driebergen Netherlands

Model name: BMS-V3

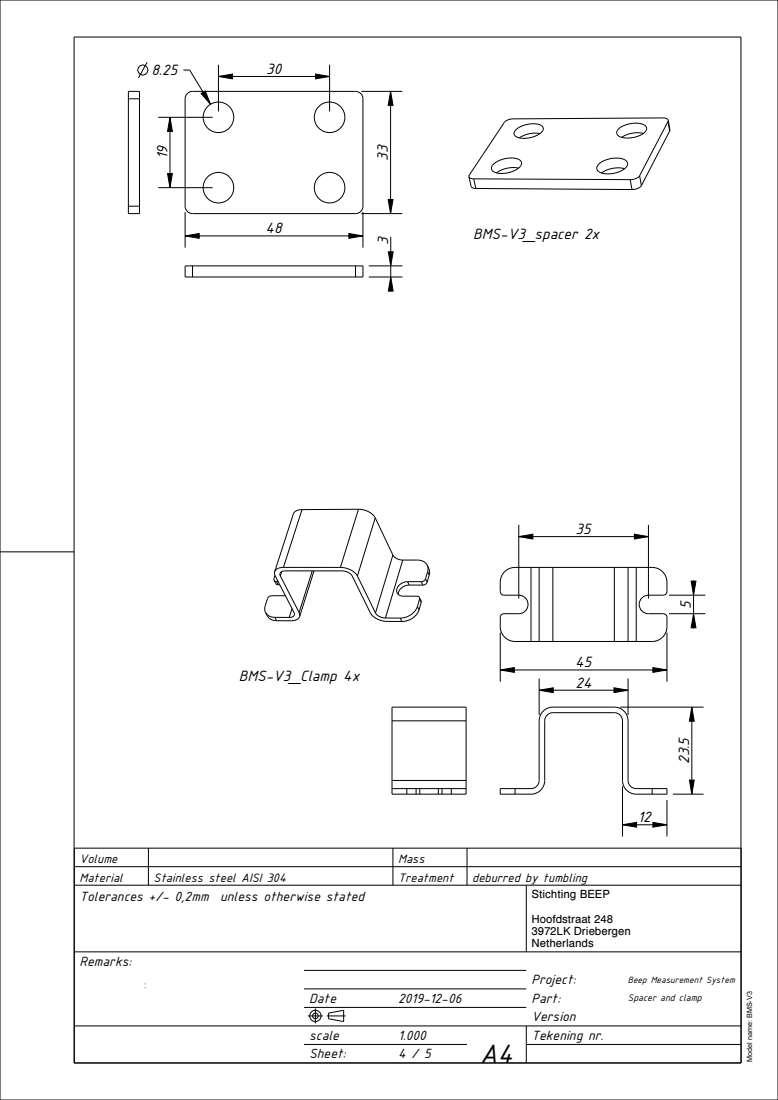
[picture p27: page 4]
Remarks:; Project:; Beep Measurement System; Date; Part:; Spacer and clamp; scale; Tekening nr.; Sheet:; BMS-V3_Clamp 4x; BMS-V3_spacer 2x

Volume | | Mass
Material | Stainless steel AISI 304 | Treatment | deburred by tumbling
Tolerances +/- 0,2mm unless otherwise stated | Stichting BEEP Hoofdstraat 248 3972LK Driebergen Netherlands

Model name: BMS-V3

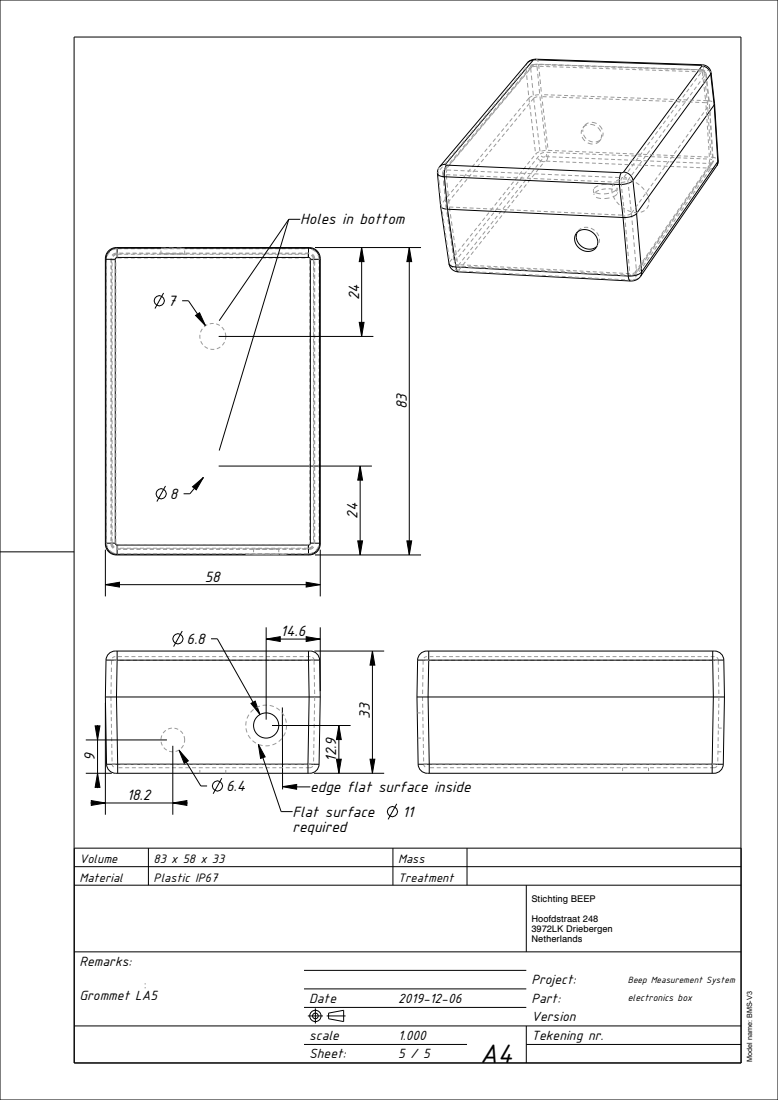
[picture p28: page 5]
Remarks:; Grommet LA5; Project:; Beep Measurement System; Date; Part:; electronics box; scale; Tekening nr.; Sheet:; Flat surface

Holes in bottom

edge flat surface inside

required

Volume | 83 x 58 x 33 | Mass
Material | Plastic IP67 | Treatment

Stichting BEEP Hoofdstraat 248 3972LK Driebergen Netherlands

Model name: BMS-V3

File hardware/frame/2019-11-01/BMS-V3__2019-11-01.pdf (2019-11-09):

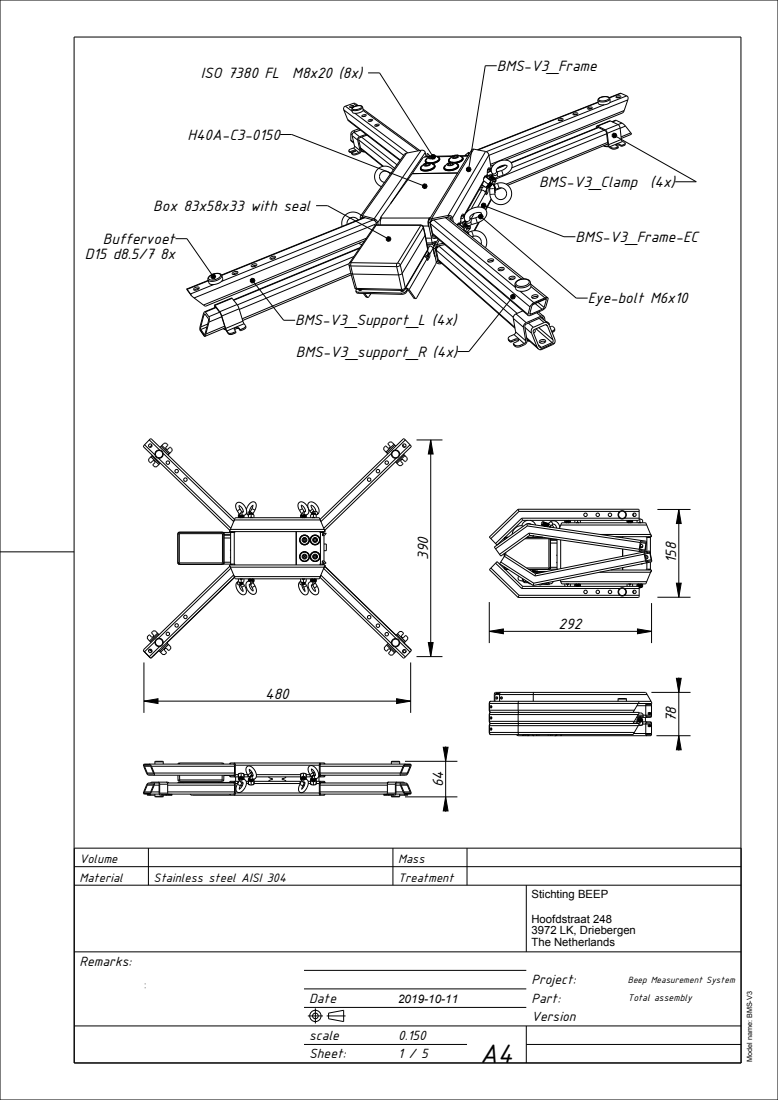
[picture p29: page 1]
Remarks:; Project:; Beep Measurement System; Date; Part:; Total assembly; Version; scale; Sheet:; Eye-bolt M6x10; BMS-V3_support_R (4x); BMS-V3_Support_L (4x); BMS-V3_Frame-EC; BMS-V3_Clamp (4x); Box 83x58x33 with seal; Buffervoet D15 d8.5/7 8x

BMS-V3_Frame ISO 7380 FL M8x20 (8x)

Volume | | Mass
Material | Stainless steel AISI 304 | Treatment

Stichting BEEP Hoofdstraat 248 3972 LK, Driebergen The Netherlands

Model name: BMS-V3

Remarks:; Project:; Beep Measurement System; Date; Part:; Frames; Sheet:; 4x Nut m6 h=1,5d; BMS-V3_FRAME_CENTRE; BMS-V3_FRAME_EC_BRACKET; BMS-V3_FRAME_TUBE; BMS-V3_Frame; BMS-V3_Frame_EC; 8x weld inside A3x12mm

Clean surface
to mount sensor
No spatter

weld centre and
two corners inside

SECTION YZ-YZ

Seam tube
removed by supplier
on same side as nut

Slots to weld in
nut m6 on 45

Volume | | Mass
Material | Stainless steel AISI 304 | Treatment | powder-coated RAL 1023 Satin
Tolerances +/- 0,2mm Angles +/-15' unless otherwise stated | Stichting BEEP Hoofdstraat 248 3972 LK, Driebergen The Netherlands

Model name: BMS-V3

Remarks:; Project:; Beep Measurement System; Date; Part:; BMS-V3_SUPPORT_L + R; Version; Sheet:; BMS-V3_SUPPORT_L; BMS-V3_SUPPORT_R; Buffer feet D15 d8.5/7

Place buffer feet in
1st and 3rd hole from
end of each support

Hole 6mm for hook
powder-coating

Weld on this corner needs to be grinded flush

Singe U butt weld all around

NB: Top surface (with holes) of supports is most important to
be completely flat for minimizing system tolerances, because
this is pushed against the inside of BMS-V3_FRAME_TUBE

Volume | | Mass
Material | Stainless steel AISI 304 | Treatment | Clean outside surface
Tolerances +/- 0,5mm Angles +/-20' unless otherwise stated | Stichting BEEP Hoofdstraat 248 3972 LK, Driebergen The Netherlands

Model name: BMS-V3

Remarks:; Project:; Beep Measurement System; Date; Part:; BMS-V3_CLAMP; scale; Sheet:

Volume | | Mass
Material | Stainless steel AISI 304 | Treatment | deburred by tumbling
Tolerances +/- 0,2mm unless otherwise stated | Stichting BEEP Hoofdstraat 248 3972 LK, Driebergen The Netherlands

Model name: BMS-V3

top; bottom; Flat surface; required; Project:; Date; Part:; scale; Sheet:; of box; for 3.5mm; Hole in bottom for temperature sensor cable

Transparent box preview
with cable weight sensor
and BMS-V3_PCB inside

Double circles: 6x screw cilinder at bottom box hole diam
3.5mm, height 5mm, 4x messing insert at corners diam 2.5mm

inside bottom box

Hole in bottom

Hole for load cell cable

Hole at back side

jack on PCB

edge flat surface inside

Volume | 83 x 58 x 33 mm | Mass
Material | Plastic IP67 water proof (e.g. PVC) | Treatment
Load cell Bosche H40A cut at 10 cm cable thickness: 5mm (Skindicht LA5 grommet) DS18b20 Temperature sensor 2m cable thickness: 3.5mm (Skindicht LA3 grommet) | Stichting BEEP Hoofdstraat 248 3972 LK, Driebergen The Netherlands

Remarks:
All sizes in mm
Cable grommets are placed inside holes
of 2x 7mm (LA5/LA3). Rubber cap is
placed inside 3.5mm jack

Beep Measurement System
electronics box

Model name: BMS-V3


















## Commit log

2019-11-09 Add partslist and pcb documentation
    [ID190222-02_BOM and Partslist.xlsx]
2020-01-11 Add firmware v1.3.2, firmware manual and updated drawings and 3D models of the hardware
    [BMS-V3_2019-11-01.stp, BMS-V3_2019-12-06.stp]
2020-02-13 Added a BOM for the sensors
    [BOM sensors.xlsx]
2020-02-28 Firmware update: bugfix for reading multiple temperature sensors and port 2 message
2020-05-22 Create BOM materials.xlsx
    Added the list of used sensors.
    [BOM materials.xlsx]
2020-06-02 Added current open source keys
2022-10-17 Two plated through-holes added in drill file
    Added two holes at the reed switch (S1) footprints (0.711mm, plated), since the reed switch is now replaced by a wired push-button for which these added holes provide strain relief.
2022-10-27 Reed switch removed from layout & from BOM
    0.8mm plated holes added for SPST push-button that replaces the reed switch
    [ID190222-03_BOM and Partslist.xlsx]
2025-01-22 PCB - Folder restructuring - Add ID190222-04
    [ID190222-02_BOM and Partslist.xlsx, ID190222-03_BOM and Partslist.xlsx]
2025-01-22 PCB - ID190222-04 - Add BOM
    [ID190222-04_BOM and Partslist.xlsx]
2025-01-22 PCB - ID190222-03 and ID190222-04 Add placement files
2025-01-22 Frame - Folder structure, add v3.7 fixed legs
    [BMS-Loadcell-spacer.dxf, BMS-V3_2019-11-02.stp, BMS-V3_2019-12-06.stp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]
